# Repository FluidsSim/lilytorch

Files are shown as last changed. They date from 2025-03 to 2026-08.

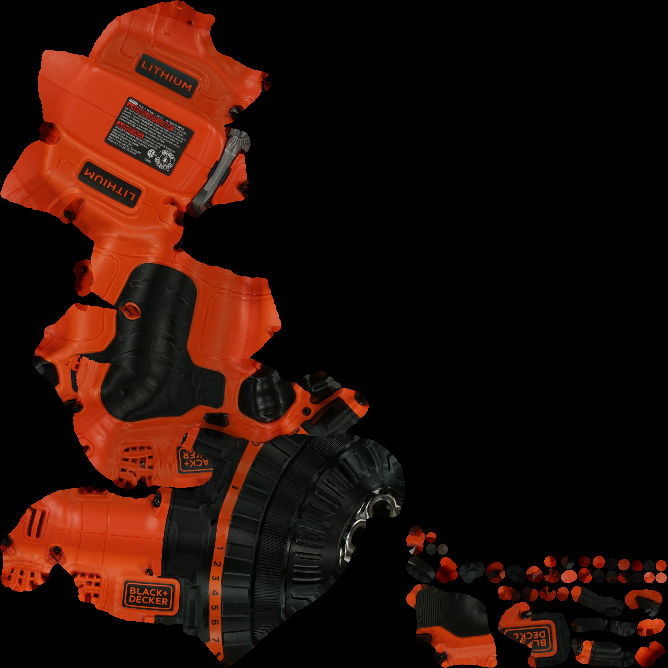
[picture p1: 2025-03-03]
lilytorch/body_solver/pytorch_volumetric_tests/tests/YcbPowerDrill/texture_map.png

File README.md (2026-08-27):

# LilyTorch

LilyTorch is a PyTorch-based 2-D/3-D incompressible-flow solver for
fluid–structure interaction. It combines a Cartesian MAC grid, BDIM2 immersed
boundaries, native C++/CUDA operators, FFT or geometric-multigrid pressure
solvers, and optional FARMS/MuJoCo coupling.

The maintained user guide, numerical documentation, API inventory, examples
index, paper links, and milestone index live in the unified
[`FluidsSim/lilytorch-docs`](https://github.com/FluidsSim/lilytorch-docs)
repository. This repository intentionally does not duplicate those pages.

## Examples

A set of examples will be made available soon. In the meantime, some simulation
examples are shown below.

<table>
<tr>
<td width="50%">

**Boat**

<video src="https://github.com/user-attachments/assets/17bb9903-24f2-4fcc-b9a0-902438b45532" width="100%" height="240" controls muted></video>

<sub>[▶ Also on YouTube](https://youtu.be/BuwlqcF3FKU)</sub>

</td>
<td width="50%">

**Submarine**

<video src="https://github.com/user-attachments/assets/08432d15-f760-4b1d-b915-560fcba9c0c9" width="100%" height="240" controls muted></video>

<sub>[▶ Also on YouTube](https://youtu.be/TZnUeeh6IvQ)</sub>

</td>
</tr>
<tr>
<td width="50%">

**Salamander — swimming 2d**

<video src="https://github.com/user-attachments/assets/084ad315-8eef-464e-81b1-3f94701fec6d" width="100%" height="240" controls muted></video>

<sub>[▶ Also on YouTube](https://youtu.be/LjBTwg80DzI)</sub>

</td>
<td width="50%">

**Zebrafish — 3-D, vorticity magnitude**

<video src="https://github.com/user-attachments/assets/42a7b2c2-9ab7-47a1-a856-ead4c0d7b4ad" width="100%" height="240" controls muted></video>

<sub>[▶ Also on YouTube](https://youtu.be/qHh5nry3F-A)</sub>

</td>
</tr>
<tr>
<td width="50%">

**Three spheres VOF**

<video src="https://github.com/user-attachments/assets/d27171a0-7b02-47c4-9880-9b576819b01f" width="100%" height="240" controls muted></video>

<sub>[▶ Also on YouTube](https://youtu.be/kHZGqutqFUI)</sub>

</td>
<td width="50%">

**1guilla robot surface swimming**

<video src="https://github.com/user-attachments/assets/07853360-651a-40a6-ac67-5831b730a184" width="100%" height="240" controls muted></video>

<sub>[▶ Also on YouTube](https://youtu.be/4YsMVhUbUNI)</sub>

</td>
</tr>
</table>

## Validation with robot experiments

### 1guilla in water - Rhodamine dye - Re~160000

<video src="https://github.com/user-attachments/assets/e63b9f63-909f-403e-aa9d-8971d2530a16" width="100%" height="600" controls muted></video>

<sub>[▶ Also on YouTube](https://youtu.be/vxCyhAP2mQc)</sub>

### 1guilla in carboxymethyl cellulose and water thick solution - Fluorescein dye - Re~100

<video src="https://github.com/user-attachments/assets/4bb6186a-d4f5-42d0-8f52-3dacf773cfbb" width="100%" height="600" controls muted></video>

<sub>[▶ Also on YouTube](https://youtu.be/748NTNWLCEs)</sub>

## Installation

Python 3.9 or newer and a C++ compiler are required. Install the appropriate
CPU or CUDA build of PyTorch first; a matching CUDA toolkit is required when
building CUDA operators.

```bash
git clone https://github.com/FluidsSim/lilytorch.git
git clone https://github.com/FluidsSim/lilytorch_examples.git

python3 -m venv .venv
source .venv/bin/activate
python -m pip install torch
python -m pip install -r lilytorch/requirements.txt
python -m pip install -e lilytorch --no-build-isolation
python -m pip install -e lilytorch_examples
```

`--no-build-isolation` is intentional: the native extension must be compiled
against the same PyTorch installation used at runtime. Set
`LILYTORCH_NO_CUDA=1` to force a CPU-only extension build.

Verify the install:

```bash
python -c "import lilytorch; from lilytorch.src import native; print(lilytorch.__version__)"
```

## FARMS/MuJoCo coupling

Initialize the pinned submodules and install the standard FARMS packages:

```bash
git -C lilytorch submodule update --init --recursive
(cd lilytorch/lilytorch/FARMS_V2 && python setup_farms.py)
```

The helper installs `farms_core`, `farms_mujoco`, and `farms_sim`. Install
`farms_amphibious` separately for cases that import it:

```bash
python -m pip install -e lilytorch/lilytorch/FARMS_V2/farms_amphibious \
  --no-build-isolation
```

## Run and test

From the directory containing both checkouts, run a maintained standalone case:

```bash
python -m lilytorch_examples.examples.standalone.runsim \
  flow_past_circle_2d.yaml
```

Run LilyTorch's companion test suite from the directory containing both
checkouts with:

```bash
python -m pytest lilytorch_examples/lilytorch_examples/tests
```

The production implementation uses native CPU/CUDA operators. There is no
separate `diffusion.py`, `kernels/` package, or selectable Python-versus-native
solver path; old `solver_method` and `use_kernels` values are compatibility
inputs only.

## License

MIT

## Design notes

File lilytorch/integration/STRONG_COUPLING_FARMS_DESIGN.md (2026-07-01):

# Strong (implicit) FSI coupling for the FARMS/MuJoCo path — design

Status: **implemented; FARMS end-to-end validation blocked by an unstable
test config** (see §16). The standalone path is implemented and validated
(`strong_coupling.py`, `fsi_rigid_body.py`, `demo_real_fsi.py`).  The
FARMS/MuJoCo implicit path is implemented in `BDIMhandler` (`_step_implicit`,
`_MujocoCheckpoint`, `_pose_source="physics"`, `_apply_forces(loads=)`); its
building blocks are individually validated, but a clean end-to-end run needs
a coupled config whose explicit baseline is stable (§16).

---

## 1. What the coupled path does today (explicit / staggered)

The dm_control runtime drives the loop. Per full step:

```
Task.before_step(action, physics):          # runs BEFORE integration
    update_sensors()
    for ext in extensions:                   # sim-extensions then animat-extensions
        ext.before_step(...)                 #   FluidExtension here -> BDIMhandler.step()
        if ext is AnimatController:           #   controller sets data.ctrl / muscle excitations
            set joint/torque/muscle ctrl
physics.step()                                # mj_step: integrate under (ctrl, xfrc_applied, contacts)
Task.after_step(physics)
```

`FluidExtension.before_step` (extensions.py) on a *full* step calls
`BDIMhandler.step(task, physics)`:

```
BDIMhandler.step:
    fs.step_(...)            # reads body poses from MuJoCo (BDIMhandler.update),
                             # advances fluid, computes loads
    self.apply_forces(...)   # assembles (F,T)+buoyancy, writes physics.data.xfrc_applied
```

Then the runtime's `physics.step()` integrates MuJoCo **once** under that
force. The fluid saw pose `pⁿ`; MuJoCo advances `pⁿ → pⁿ⁺¹` under `Fⁿ`; the
fluid never re-solves at `pⁿ⁺¹`. This is explicit Dirichlet–Neumann
staggering — unstable when added (displaced-fluid) mass ≳ body mass, which
is exactly why `force_relaxation` (a constant low-pass on `F`) exists. It
damps but does not remove the instability.

## 2. Goal

Replace the single force push with a **converged fixed-point iteration**
per step, accelerated by the existing `fsi_coupling` accelerators
(Aitken / IQN-ILS), so the coupling is stable independent of mass ratio
and `force_relaxation` is no longer needed.

## 3. The architectural constraint and the key idea

`BDIMhandler.step()` runs **inside** `before_step`, *before* the runtime's
`physics.step()`. The runtime owns the one real integration. We must not
double-integrate.

**Key idea — "leave the converged force, let FARMS integrate once"
(Option A).** Run the whole fixed-point loop *internally* inside
`BDIMhandler.step()`, using throwaway MuJoCo integrations for *prediction*
only, each undone by a checkpoint restore. When converged, restore MuJoCo
to the **start-of-step** state `sⁿ` and leave `xfrc_applied` holding the
**converged** force `F*`. Then `before_step` returns and the runtime does
its single `physics.step()`, integrating `sⁿ` under `F*` → the converged
end state. Net external effect: `xfrc_applied` carries `F*` instead of the
explicit one-shot `Fⁿ`. The FARMS control/integration pipeline is otherwise
untouched.

This is non-invasive: no changes to the runtime, the task loop, or the
controller — only `BDIMhandler.step()` gains an implicit branch.

## 4. Coupling variable

Two valid choices; **v1 recommends coupling on the force** (the Neumann
data), because it is the smallest vector and a direct upgrade of the
existing `force_relaxation`:

- **`x = applied loads`** per coupled body `[Fx,Fy,Fz,Tx,Ty,Tz] × B`
  (dim `6B`). The fixed-point map is

  ```
  H(x):  restore(mj, fluid) to start
         write x (+ buoyancy@candidate-pose) to xfrc_applied
         mj_step                      # structure: loads -> predicted pose/vel s̃
         mj_forward                   # refresh link xpos/xquat/cvel at s̃
         fluid solve at s̃ (BDIMhandler.update reads s̃ -> SDF + no-slip)
         x̃ = get_loads(+buoyancy)     # fluid -> new loads
  residual r = x̃ - x ; accelerate.
  ```

  At the fixed point the applied force equals the force the fluid produces
  for the pose that force induces — i.e. fully consistent.

- *(alternative)* **`x = generalized state (qpos, qvel)`** of the coupled
  animats. More "monolithic", but larger and needs care differencing the
  floating-base quaternion in the residual. Keep as a fallback if force
  coupling is found to converge slowly for highly articulated swimmers.

The accelerator vectors are tiny (`6B`, or tens of DOFs), so the IQN-ILS
QR solve is trivial — reuse `fsi_coupling.IQNILS` unchanged.

## 5. Checkpoint primitive (MuJoCo 3.3.7)

Use `mjSTATE_INTEGRATION` — it bundles qpos, qvel, act, time,
`qacc_warmstart`, ctrl, `qfrc_applied`, `xfrc_applied`, mocap, eq_active —
everything needed to reproduce an integration step bit-for-bit.

```python
import numpy as np, mujoco

class _MujocoCheckpoint:
    SPEC = mujoco.mjtState.mjSTATE_INTEGRATION

    def __init__(self, physics):
        self.m = physics.model.ptr
        self.d = physics.data.ptr
        self.n = mujoco.mj_stateSize(self.m, self.SPEC)
        self.buf = np.zeros(self.n, dtype=np.float64)

    def save(self):
        mujoco.mj_getState(self.m, self.d, self.buf, self.SPEC)
        return self.buf.copy()

    def restore(self, state):
        mujoco.mj_setState(self.m, self.d, state, self.SPEC)
        mujoco.mj_forward(self.m, self.d)   # refresh derived quantities
```

Fluid checkpoint reuses the existing pattern (clone `u0,v0,w0,p0`), exactly
as `FluidSolverAdapter.snapshot/restore`.

## 6. Algorithm — implicit `BDIMhandler.step()`

```python
def step_implicit(self, task, physics):
    fs   = self.fluid_solver
    it   = self.iteration
    t    = it * self.pars["solver"]["dt"]
    acc  = self.accelerator                 # fsi_coupling accelerator
    ckpt = self._mj_ckpt                     # _MujocoCheckpoint(physics)

    mj_n    = ckpt.save()                    # start-of-step MuJoCo state
    fluid_n = self._fluid_snapshot()         # clone u0,v0,w0,p0
    x = self._read_loads_vector(physics)     # initial guess: last step's loads
                                             # (0 on the first step)
    x_tilde, converged = x, False
    for k in range(1, self.max_iter + 1):
        # ---- restore both sides to start of step ----
        ckpt.restore(mj_n)
        self._fluid_restore(fluid_n)

        # ---- structure: predict pose/vel under candidate loads x ----
        self._write_loads_vector(physics, x, pose_for_buoyancy=mj_n)
        mujoco.mj_step(ckpt.m, ckpt.d)       # one full step (cb_sub_steps==1)
        mujoco.mj_forward(ckpt.m, ckpt.d)    # refresh link kinematics at s̃

        # ---- fluid: solve at predicted pose s̃ -> new loads x̃ ----
        fs.advance_and_compute_loads(fs.u0, fs.v0, fs.p0, it, t,
                                     w_vel=getattr(fs, "w0", None))
        x_tilde = self._read_loads_vector(physics, from_solver=True)

        # ---- residual + acceleration ----
        res = acc.residual_norm(x, x_tilde)
        self.last_iters, self.last_residual = k, res
        if res < self.tol * (1.0 + np.linalg.norm(x)):
            converged = True
            break
        if not np.isfinite(res):
            break
        x = acc.relax(x, x_tilde)

    acc.finalize_timestep()

    # ---- commit (Option A): leave MuJoCo at sⁿ with the converged force ----
    ckpt.restore(mj_n)
    self._write_loads_vector(physics, x_tilde, pose_for_buoyancy=mj_n)
    self._cache_forces_for_substeps(x_tilde)   # so apply_forces() re-applies F* on substeps
    fs.finalize_step(fs.u0, fs.v0, fs.p0, it,
                     w_vel=getattr(fs, "w0", None))   # plot/free-surface/release ONCE

    if not converged:
        self._handle_nonconvergence(k)             # see §9
    self.iteration += 1
```

Helpers:

- `_read_loads_vector(physics, from_solver=False)`:
  when `from_solver`, assemble from `fs.get_loads()` (the per-body
  `(F,T)`); otherwise read back what is currently in `xfrc_applied` for the
  coupled links (used for the initial guess). Flatten to `6B`.
- `_write_loads_vector(physics, x, pose_for_buoyancy)`: the body-facing
  half of the existing `_apply_forces` — scatter `x` into
  `xfrc_applied[ind, :]` for each coupled link, adding buoyancy computed at
  the **candidate** pose (reuse the existing buoyancy block). This is the
  only place that touches `xfrc`.
- `_cache_forces_for_substeps`: store `F*` in the same buffers
  `apply_forces()` reads, so intermediate MuJoCo substeps re-apply `F*`.

Note the fluid solve uses `advance_and_compute_loads` / `get_loads` /
`finalize_step` — the **same** drift-free methods the standalone
`FluidSolverAdapter` calls. `BDIMhandler.update` (which reads poses from
`physics`) runs inside `advance_and_compute_loads` via
`composite_body.update`, so it automatically sees the predicted pose `s̃`.

## 7. Requirements / constraints

1. **`cb_sub_steps == 1` for implicit mode.** The fluid advances once per
   full step; the prediction does one `mj_step`. With `cb_sub_steps > 1`
   the real integration is several substeps under the held force, so the
   prediction must loop `cb_sub_steps` `mj_step`s (re-applying the held
   force each) to match. v1 asserts `cb_sub_steps == 1`; the generalization
   is a `for _ in range(cb_sub_steps): mj_step` in the predict block.

2. **Order `FluidExtension` *after* the `AnimatController`.** The controller
   sets `data.ctrl` inside the same `before_step` pass; if Fluid runs first,
   the prediction `mj_step` uses *stale* ctrl. Putting Fluid last (or
   pre-computing the excitations, which are open-loop functions of
   `(iteration, time)`) makes the prediction use the same actuation the
   real step will use. Document/auto-check in `FluidExtension.from_options`.

3. **Buoyancy is pose-dependent** → recompute it inside
   `_write_loads_vector` at the candidate pose each sweep (the existing
   buoyancy block already reads `comp.com_pos`, which reflects the pose
   after `BDIMhandler.update`).

4. **Determinism.** `mjSTATE_INTEGRATION` includes `qacc_warmstart`, so the
   constraint solver warm-starts identically each restore → the prediction
   `mj_step` and the runtime's real `mj_step` produce identical `s̃` for
   identical `(sⁿ, ctrl, xfrc)`. Verify this equality once in validation
   (it is the correctness anchor for Option A).

## 8. Config surface

```yaml
body:
  coupling:
    scheme: implicit          # "explicit" (default, today) | "implicit"
    accelerator: iqn-ils      # iqn-ils | aitken | constant
    reuse: 2                  # IQN-ILS time-window reuse
    tol: 1.0e-4               # relative interface-residual tolerance
    max_iter: 30
    # force_relaxation is ignored when scheme == implicit
```

`BDIMhandler.__init__` builds `self.accelerator =
fsi_coupling.make_accelerator(...)`, `self._mj_ckpt`, and binds
`self.step = self.step_implicit if scheme == "implicit" else self.step_explicit`
(the current `step` becomes `step_explicit`, unchanged).

## 9. Edge cases & robustness

- **Non-convergence**: if `max_iter` is hit, fall back to the
  last-accepted `x_tilde` (best effort) and log a warning with the residual.
  Optionally trigger a one-step `force_relaxation`-style damped apply as a
  safety net. Never propagate NaNs — `check_explosion` still runs in
  `finalize_step`.
- **Contacts** (sphere near a wall, paddling on ground): handled naturally
  by `mj_step` in the prediction; no special treatment. The added
  stiffness can slow convergence — IQN-ILS reuse helps.
- **Multiple animats / partial coupling**: `_read/_write_loads_vector`
  iterate the same `comp.bodies / body_ids` the explicit path already uses;
  the coupling vector is the concatenation over coupled links only.
- **Cost**: `N` fluid solves per step (N = sweeps). Expect `N≈2–4` after
  the first step thanks to IQN-ILS reuse; the first step of a sim costs
  more. This is the price of stability; it replaces sims that diverge or
  need tiny `dt` + `force_relaxation`.

## 10. Reuse of existing code

- Accelerators: `fsi_coupling.{IQNILS,AitkenRelaxation,ConstantUnderRelaxation}`
  — unchanged.
- Fluid stepping: `FluidSolver.advance_and_compute_loads / get_loads /
  finalize_step` — unchanged (already used by `FluidSolverAdapter`).
- Force assembly/scatter + buoyancy: factor the body-facing half of the
  current `_apply_forces` into `_write_loads_vector` so explicit and
  implicit share it.

## 11. Validation plan

1. **Determinism check** (§7.4): one internal predict `mj_step` vs the
   runtime's real `mj_step` from the same checkpoint must give identical
   `qpos/qvel`. Anchors Option A.
2. **Single sphere drop** (`single_sphere_drop_coquerelle` /
   `_gazzola`): run explicit (current) vs implicit. Expect implicit to (a)
   run stably with the true `rho_body` (no `bdim_mu0_projection` / equal-
   density workaround), (b) remove the iteration-~12,500 blow-up, (c) match
   the published terminal velocity / `Cd(Re)`. Report sweeps/step.
3. **1guilla full tank**: confirm implicit removes the need for
   `force_relaxation` even with `convexify=True` overlap (see
   `project_convexify_overlap_instability`), or quantify the remaining gap.

## 12. Open questions

- Force-coupling vs state-coupling convergence for highly articulated
  swimmers (many controlled joints): start with force; switch the coupling
  vector if needed (the accelerator is agnostic).
- Whether to sub-iterate the *whole* animat state or only the floating
  base + wetted-link velocities (reduce vector size / ignore stiff
  controlled joints in the interface residual).
- Interaction with the interactive viewer (which can clear `xfrc`): the
  per-substep `apply_forces` re-application already handles this; confirm it
  still holds with Option A.
```

---

## 13. Design review — findings & required revisions

Reviewed against the actual code paths. Two **blocking** issues invalidate
the §6 algorithm as written; several minor corrections follow.

### BLOCKER 1 — the fluid reads FARMS *sensor buffers*, not `physics.data`

`BDIMhandler.update → gather_data(iteration)` (BDIMhandler.py:343) reads
poses/velocities from `exp_data.sensors.links.com_positions()[iteration]`
(and `urdf_*`, `*_velocities`), **not** from `physics.data.xpos/xquat/cvel`.
Those sensor arrays are written by `Task.update_sensors(physics)`
(task.py:249, `index = iteration % buffer_size`), called once at the top of
`Task.before_step`.

Consequence: an internal `mj_step` + `mj_forward` updates `physics.data`
but **not** what the fluid reads — the fluid would keep solving at the
start-of-step pose every sweep, and the coupling could never converge to a
moved pose.

**Revision:** after each prediction `mj_step`, call
`task.update_sensors(physics, links_only=True)` to push the predicted pose
`s̃` into the sensor buffer that `gather_data` reads. The corrected sweep:

```
restore(mj→sⁿ, fluid→fluidⁿ)
write candidate force x → xfrc
mj_step ; mj_forward                          # physics.data := s̃
task.update_sensors(physics, links_only=True) # sensor buffer[it] := s̃   ← ADDED
fs.advance_and_compute_loads(...)             # gather_data now reads s̃
x̃ = get_loads(+buoyancy)
```

Also note: the MuJoCo checkpoint (`mjSTATE_INTEGRATION`) does **not** cover
the FARMS `AnimatData` sensor buffers. We don't need to restore them
(each sweep overwrites buffer[it] via `update_sensors`), but be aware
buffer[it] is left holding the last `s̃` after the step (see Minor 3).

### BLOCKER 2 — the "single `mj_step`" prediction is unverified

The real integration is `self._env.step()` → dm_control
`physics.step(n_sub_steps)` (simulation.py:270/311/333), where
`n_sub_steps = physics.num_sub_steps` and there is also a `legacy_step`
toggle (simulation.py:58) — *separate from* FARMS `cb_sub_steps`. So the
real step may be **multiple** `mj_step`s, and possibly a custom stepping
path.

**Revision:** the prediction must replicate the real integration exactly,
i.e. `n_sub_steps × (cb_sub_steps==1)` `mj_step`s through the same path the
runtime uses (prefer calling `physics.step(n_sub_steps)` on the checkpointed
data, not a bare `mj_step`, unless `legacy_step` changes that). The §11.1
**determinism check is therefore a blocking prerequisite, not a nicety**:
confirm `predict-integration(sⁿ, ctrl, xfrc) == runtime-integration` to
machine precision before trusting Option A. Resolve `num_sub_steps`,
`cb_sub_steps`, and `legacy_step` for the target sphere-drop config first.

### Minor 1 — commit `x`, not `x_tilde`

At convergence the fluid's committed solve was performed at pose
`s̃ = integrate(sⁿ, x)` where `x` is the **last candidate** force (the
prediction used `x`, not `x̃`). To keep {committed force, fluid pose,
FARMS integration} mutually consistent, commit **`x`** to `xfrc` (FARMS then
reproduces exactly the `s̃` the fluid solved at). `x ≈ x̃` within `tol`, so
the difference is small, but `x` is the correct choice. (Fix the §6
pseudocode: `_write_loads_vector(physics, x, ...)`.)

### Minor 2 — buoyancy is outside the coupling vector

Buoyancy is pose-dependent and recomputed each sweep at write time, so the
interface residual is on the **hydrodynamic** load only. This is fine
(buoyancy is a deterministic function of the converging pose), but state it
explicitly and make sure `get_loads` (hydro) and the buoyancy add are not
double-counted.

### Minor 3 — sensor buffer left at `s̃` after commit (logging)

Because Option A restores MuJoCo to `sⁿ` but the sensor buffer at `it` holds
the last prediction `s̃`, the *logged* link pose at iteration `it` is the
end-of-step prediction rather than the start pose. Decide intended
semantics; if start-of-step logging is desired, re-run
`update_sensors(physics)` after the final `ckpt.restore(mj→sⁿ)`.

### Minor 4 — iteration-index alignment

`gather_data` indexes with `BDIMhandler.iteration`; `update_sensors`/buffers
index with `Task.iteration`. They both start at 0 and advance once per full
step, but the implicit path must keep them aligned (and respect
`buffer_size`, given `gather_data` uses a raw `[iteration]` index while
writes use `iteration % buffer_size`).

### Minor 5 — cost

Each sweep now also runs `update_sensors` (links) in addition to a full
fluid solve and `n_sub_steps` `mj_step`s. Still `O(sweeps)`; acceptable, but
the per-sweep constant is higher than the §9 estimate implied.

### What still holds

- Option A (run the loop inside `before_step`; leave `sⁿ` + converged force;
  FARMS integrates once) remains valid **with** the `update_sensors`
  propagation and the exact-integration replication added.
- Checkpoint primitive (`mjSTATE_INTEGRATION`) — correct/sufficient for the
  MuJoCo side (covers qpos/qvel/act/time/warmstart/ctrl/qfrc/xfrc); just
  remember it excludes the FARMS sensor buffers.
- Force coupling vector, `fsi_coupling` accelerator reuse, and the
  `advance_and_compute_loads / get_loads / finalize_step` fluid path —
  unchanged and valid.
- Requirements §7 (cb_sub_steps==1, Fluid ordered after the controller,
  pose-dependent buoyancy) — still required; add "resolve num_sub_steps /
  legacy_step" to the list.

### Recommended first implementation step (unchanged, now justified)

Implement `_MujocoCheckpoint` + the **determinism check** against a real
sphere-drop config, explicitly resolving `num_sub_steps`, `cb_sub_steps`,
`legacy_step`, and confirming `update_sensors`→`gather_data` round-trips the
predicted pose. Only once that anchor passes is the rest safe to wire.

---

## 14. Revised data path — read `physics.data` directly (supersedes Blocker 1)

The cleaner fix for Blocker 1 is to **read link kinematics straight from
`physics.data`** in the implicit path, instead of the FARMS sensor buffers.
This is exactly what FARMS' own `SwimmingExtension` does
(`swimming/extension.py:205`: `physics.data.xmat[indices]`), and the
per-link MuJoCo body-id map is the one BDIMhandler already uses for forces:
`indices = task.maps[animat_i]['sensors']['data2xfrc']`.

Field mapping (MuJoCo → what `gather_data` returns), with FARMS unit
scaling so values match the SI sensor path:

| gather_data output | physics.data source | units |
|---|---|---|
| `urdf_pos` (link frame origin) | `data.xpos[ind]` | `÷ units.meters` |
| `R` (link orientation) | `data.xmat[ind].reshape(3,3)` | — |
| `com_pos` (link COM) | `data.xipos[ind]` | `÷ units.meters` |
| `lin_vel` (COM linear vel) | `mj_objectVelocity(... mjOBJ_XBODY, ind, flg_local=0)` linear part | `÷ units.velocity` |
| `ang_vel` (COM angular vel) | same call, angular part | `÷ (units.velocity/units.meters)` |

Because the internal prediction (`physics.step` / `mj_step` + `mj_forward`)
updates `physics.data`, the fluid now sees the predicted pose **with no
`update_sensors` round-trip**. This removes the §13 Blocker-1 workaround and
Minor 3/4 (no sensor-buffer mutation, no buffer/iteration-index coupling).
Revised sweep:

```
restore(mj→sⁿ, fluid→fluidⁿ)
write candidate force x → xfrc
physics.step(n_sub_steps)            # SAME call the runtime uses (see §15)
fs.advance_and_compute_loads(...)    # gather_data(source="physics") reads physics.data = s̃
x̃ = get_loads
```

**Risk to control:** `gather_data` is shared with the *explicit* (validated)
path. To avoid silently changing existing coupled sims, **do not replace**
the sensor path — *parametrize* it: `gather_data(iteration, source="sensors"
| "physics")`, explicit keeps `"sensors"`, implicit uses `"physics"`. Then
add an **equivalence test**: at the start-of-step pose `sⁿ`, the two sources
must return matching `(urdf_pos, R, com_pos, lin_vel, ang_vel)` to tight
tolerance. Positions/orientation are trivial (`xpos/xipos/xmat`); the
**velocities are the subtle part** — match the exact `mj_objectVelocity`
convention (com-based, global frame) and unit scaling FARMS uses to fill the
sensors. The equivalence test is the gate for the data path; the §11.1
determinism test is the gate for the integration.

## 15. Blocker 2, downgraded — use the runtime's own integration call

Rather than reimplement the integration with a bare `mj_step` (and guess at
`num_sub_steps` / `legacy_step`), the prediction should invoke the **same**
call the dm_control runtime uses after `before_step`:
`physics.step(self._env._n_sub_steps)` (simulation.py:270 → dm_control
`Environment.step` → `physics.step(n_sub_steps)`). On the checkpointed data
this reproduces the real integration by construction — there is nothing to
re-derive. Blocker 2 then reduces to a single assertion (§11.1): predict via
`physics.step(n)`, read `s̃`; restore; let the runtime step; assert the
runtime's `s̃` equals the predicted one. The only residual is whether
`legacy_step=True` routes through a non-`physics.step` path — which the
assertion catches immediately. So: **Blocker 2 is "use the same call + one
test", not a redesign.**

---

## 16. Implementation status (steps 1–3 done; FARMS validation blocked)

**Implemented & validated (building blocks):**
- §1 pose-source data path: `gather_data(_pose_source="physics")` + `_gather_data_physics`. Equivalence to the sensor path **verified on a real farmsim sphere-drop run** (iters 0,1 PASS). `test_pose_source.py` (3 convention tests pass).
- §5 checkpoint: `_MujocoCheckpoint` (mjSTATE_INTEGRATION). Determinism/reproducibility verified — `test_mujoco_checkpoint.py` (3 pass).
- `_apply_forces` refactored to accept a `loads=` override (shared buoyancy/scaling/write); explicit `loads=None` path is byte-identical (confirmed: original and refactored both explode coquerelle at iter ~5, i.e. no regression).
- §6 implicit step: `_step_implicit` (force coupling, Option A, checkpoint/restore loop, IQN-ILS via `fsi_coupling`), config surface `body.coupling.{scheme,accelerator,reuse,tol,max_iter,predict_substeps}`. Dispatched from `step()`; explicit path renamed `_step_explicit` (unchanged).

**FARMS end-to-end validation: BLOCKED by config, not implemented bug.**
- The only coupled config exercised (`single_sphere_drop_coquerelle`) has an **unstable explicit baseline**: the *original* (pre-work) code explodes at iteration 5 (`|u|_max=2.4e6 > 100`). It is one of the known instability cases (see `INSTABILITY_ANALYSIS`, `project_bdim_pressure_band`), so it cannot validate the implicit scheme.
- Under implicit coupling the same config diverges at step 0 (force → ~1e6): a single in-loop fluid solve at the *predicted moving-body* pose drives `|u|` to ~1e5 in one solve (gathered velocity `[0,-0.098]` is correct; gravity_z=-980 ⇒ cm units; pose correct). `bdim_mu0_projection: True` did **not** change this. Because the explicit baseline is itself unstable, the step-0 divergence cannot be cleanly attributed to an implicit bug vs the config's inherent fragility (the implicit scheme imposes the moving body immediately, hitting the instability sooner than explicit's lagged ramp-up).

**Next steps to actually validate:**
1. Find/produce a **stable coupled config** (explicit baseline runs without `check_explosion`): e.g. a swimmer at moderate Re, or a sphere-drop with grid/dt/eps tuned so the explicit baseline is at least marginally stable. Run explicit vs implicit and compare.
2. If a target is meant to be the *unstable* sphere-drop (the case the project wants implicit to cure), first establish that implicit *converges* per step on a stable case, then test whether it tames the unstable one — instrument the per-sweep residual to confirm the fixed-point map is contractive (it should be for `rho_body/rho>1`).
3. Resolve the impulsive-startup question: whether a single solve at the predicted moving-body pose on the start-of-step fluid field is well-posed, or whether the first sweep should solve at the start pose (explicit predictor) before predicting.

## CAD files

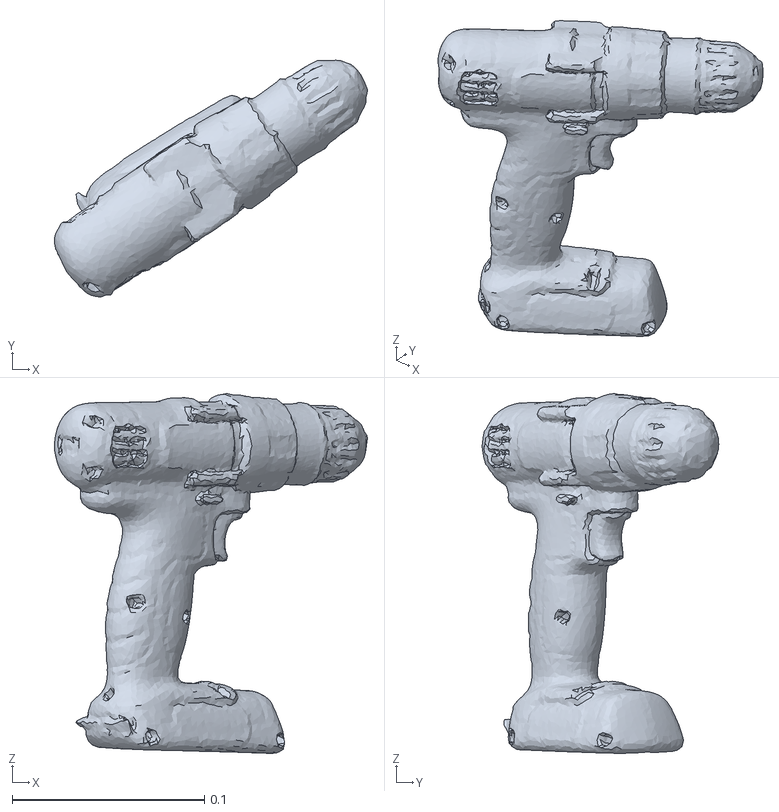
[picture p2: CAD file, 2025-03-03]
lilytorch/body_solver/mesh_examples/textured_simple_reoriented.obj
0.163 x 0.123 x 0.187

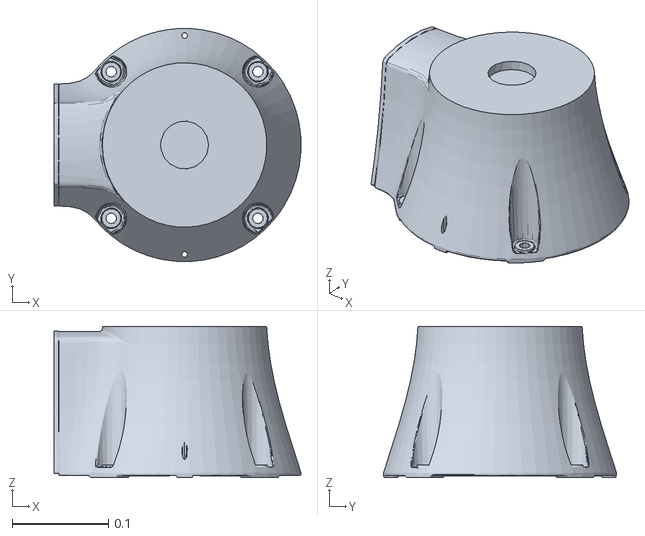
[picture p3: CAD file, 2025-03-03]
lilytorch/body_solver/mesh_examples/URDF_models/meshes_iiwa/link_0.stl
0.257 x 0.243 x 0.158

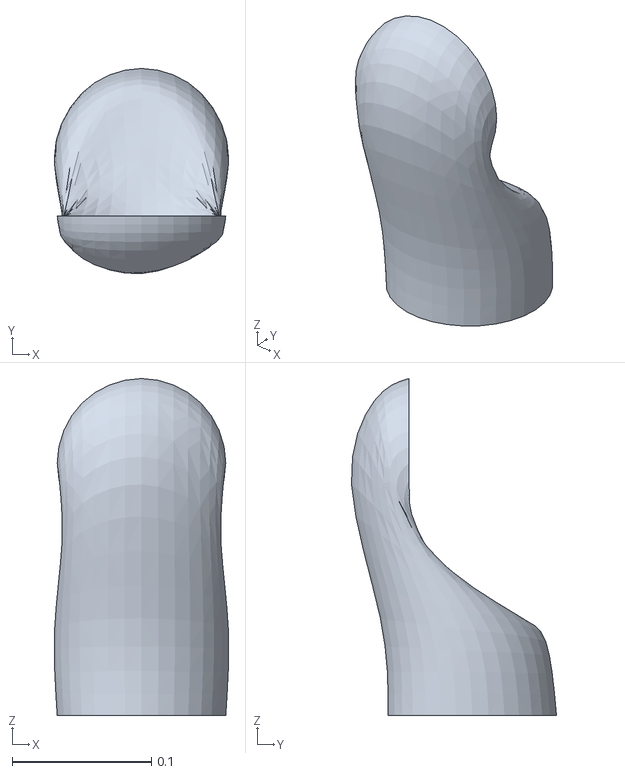
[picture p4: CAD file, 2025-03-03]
lilytorch/body_solver/mesh_examples/URDF_models/meshes_kuka_lwr/arm_segment_last.stl
0.125 x 0.147 x 0.242

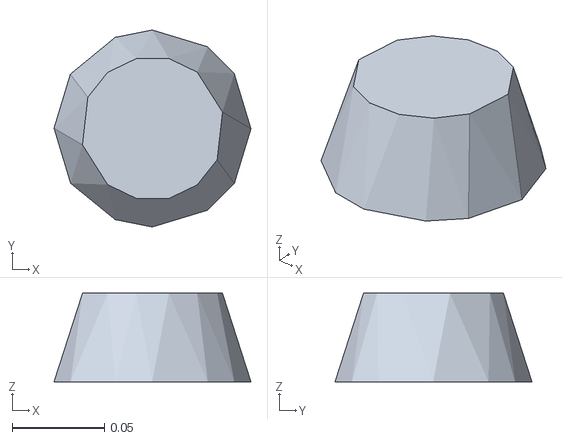
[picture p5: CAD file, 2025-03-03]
lilytorch/body_solver/mesh_examples/URDF_models/meshes_kuka_lwr/convex/arm_flanche_convex.stl
0.107 x 0.107 x 0.048

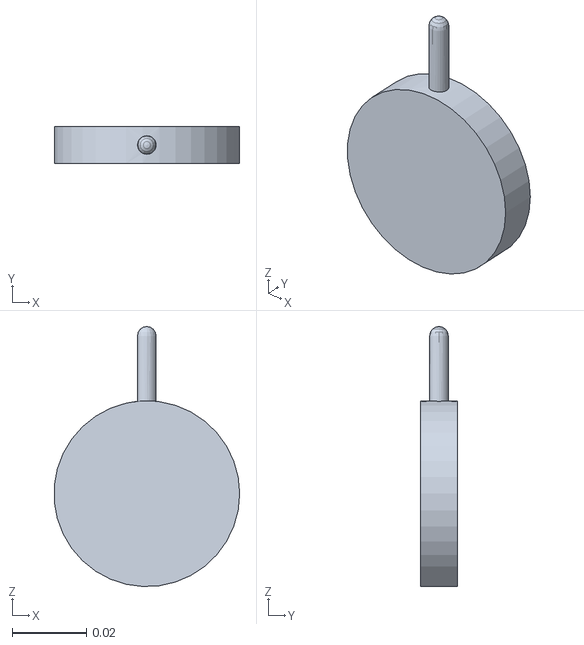
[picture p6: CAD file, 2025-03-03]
lilytorch/body_solver/pytorch_volumetric_tests/tests/probe.obj
0.0499 x 0.01 x 0.07

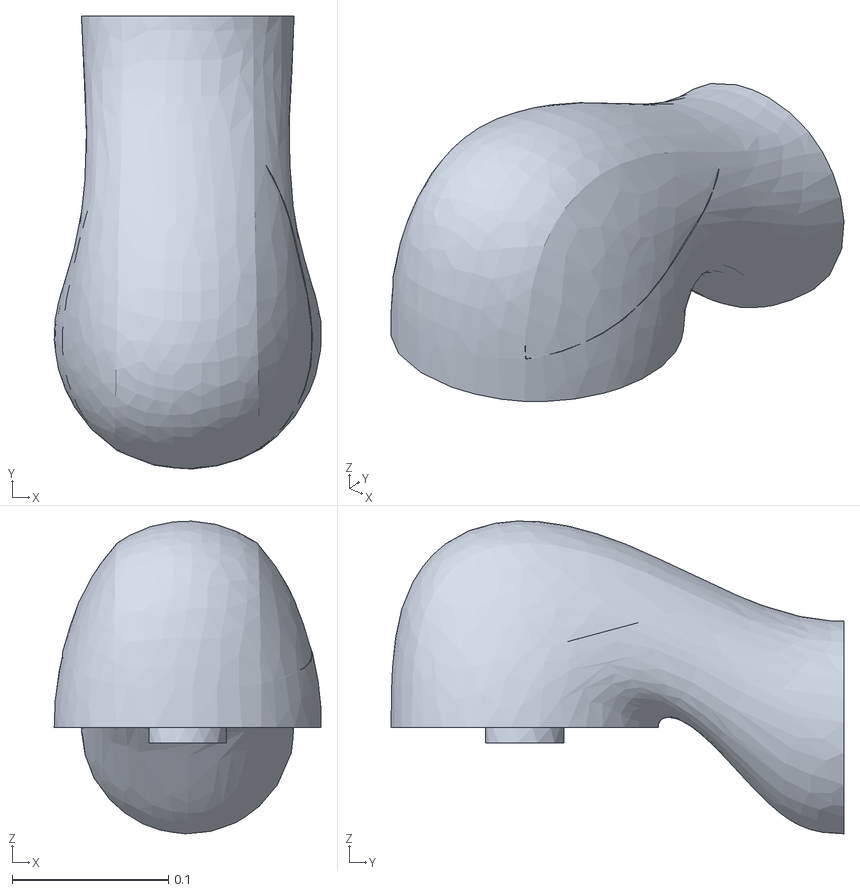
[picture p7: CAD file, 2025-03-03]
lilytorch/body_solver/mesh_examples/URDF_models/meshes_iiwa/link_2.stl
0.171 x 0.29 x 0.2

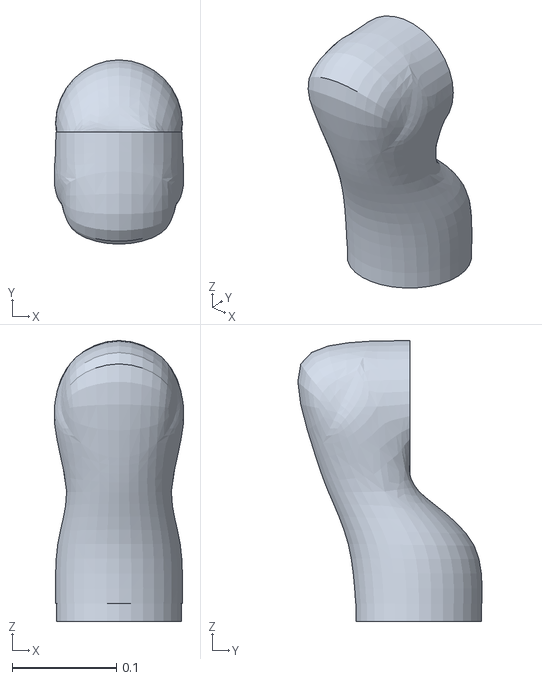
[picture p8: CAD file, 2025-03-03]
lilytorch/body_solver/mesh_examples/URDF_models/meshes_kuka_lwr/arm_segment_b.stl
0.124 x 0.177 x 0.269

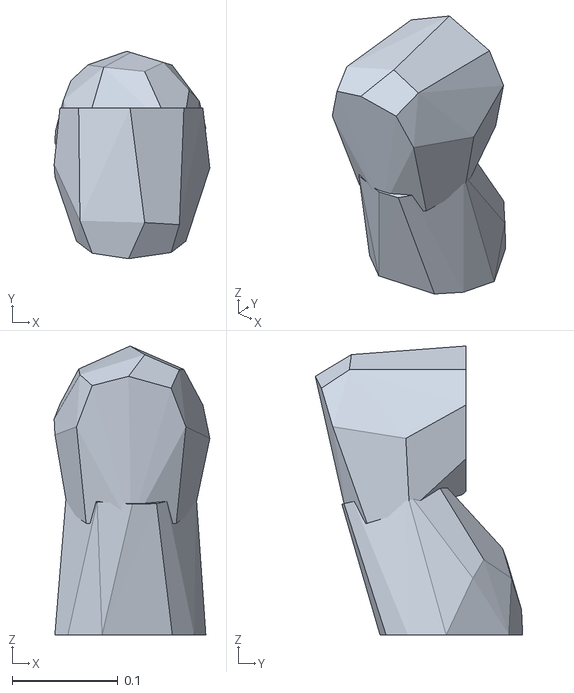
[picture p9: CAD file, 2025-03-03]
lilytorch/body_solver/mesh_examples/URDF_models/meshes_kuka_lwr/convex/arm_segment_a_convex.stl
0.148 x 0.197 x 0.274

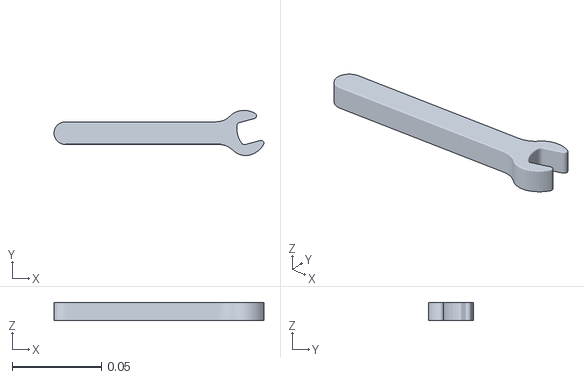
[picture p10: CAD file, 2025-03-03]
lilytorch/body_solver/pytorch_volumetric_tests/tests/offset_wrench_nogrip.obj
0.117 x 0.0253 x 0.0101

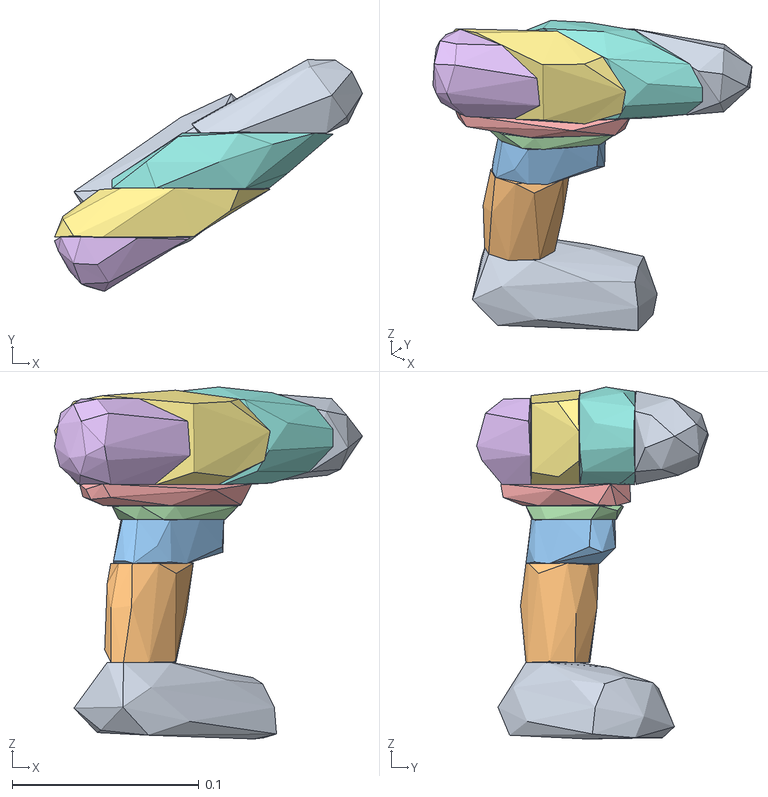
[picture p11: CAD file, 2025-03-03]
lilytorch/body_solver/pytorch_volumetric_tests/tests/YcbPowerDrill/collision_vhacd.obj
0.165 x 0.124 x 0.188
textured_simple_reoriented.004_hull_1_textured_simple_reoriente
textured_simple_reoriented.004_hull_2_textured_simple_reoriente
textured_simple_reoriented.004_hull_3_textured_simple_reoriente
textured_simple_reoriented.004_hull_4_textured_simple_reoriente
textured_simple_reoriented.004_hull_5_textured_simple_reoriente
textured_simple_reoriented.004_hull_6_textured_simple_reoriente
textured_simple_reoriented.004_hull_7_textured_simple_reoriente
textured_simple_reoriented.004_hull_8_textured_simple_reoriente
textured_simple_reoriented.004_hull_9_textured_simple_reoriente

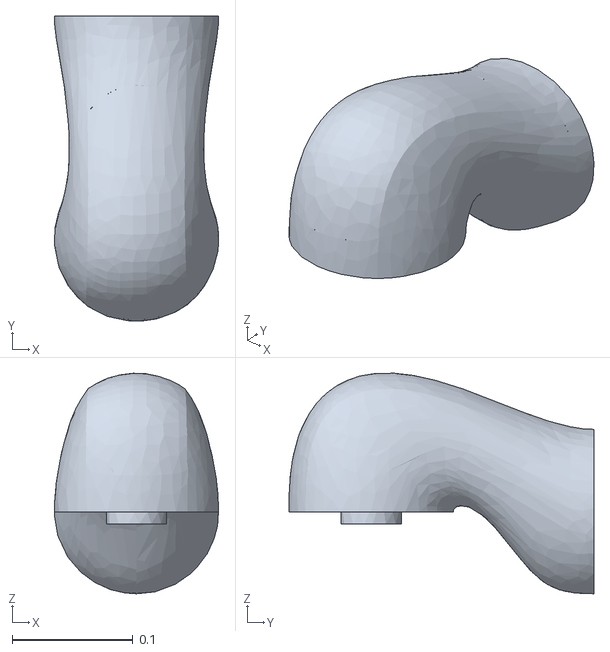
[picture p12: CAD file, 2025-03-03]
lilytorch/body_solver/mesh_examples/URDF_models/meshes_iiwa/link_4.stl
0.136 x 0.252 x 0.183

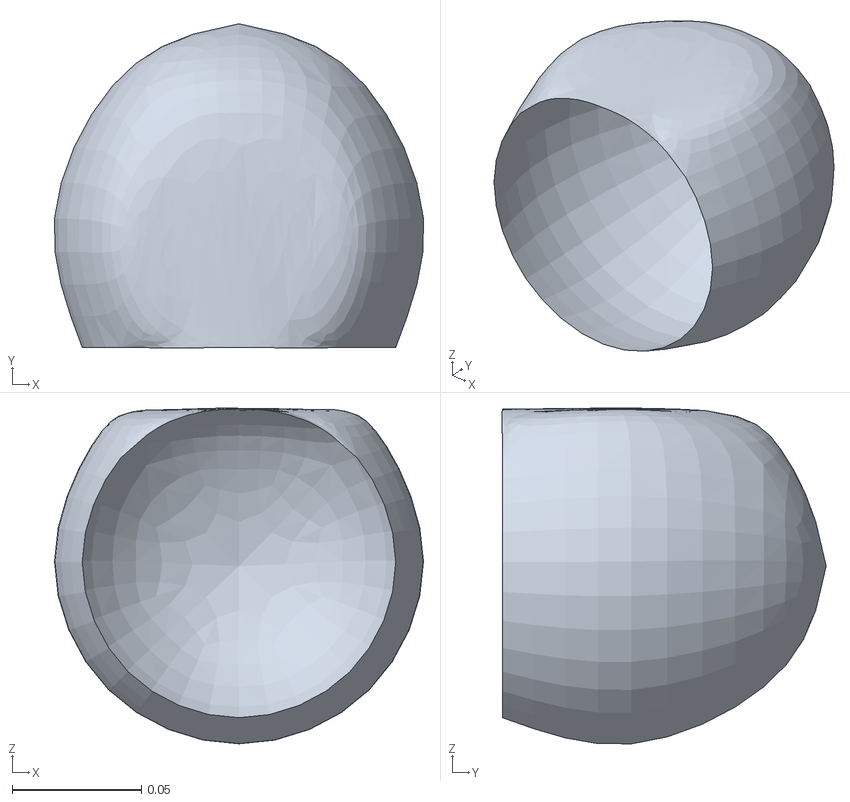
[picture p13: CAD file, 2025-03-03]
lilytorch/body_solver/mesh_examples/URDF_models/meshes_kuka_lwr/arm_wrist.stl
0.143 x 0.125 x 0.13

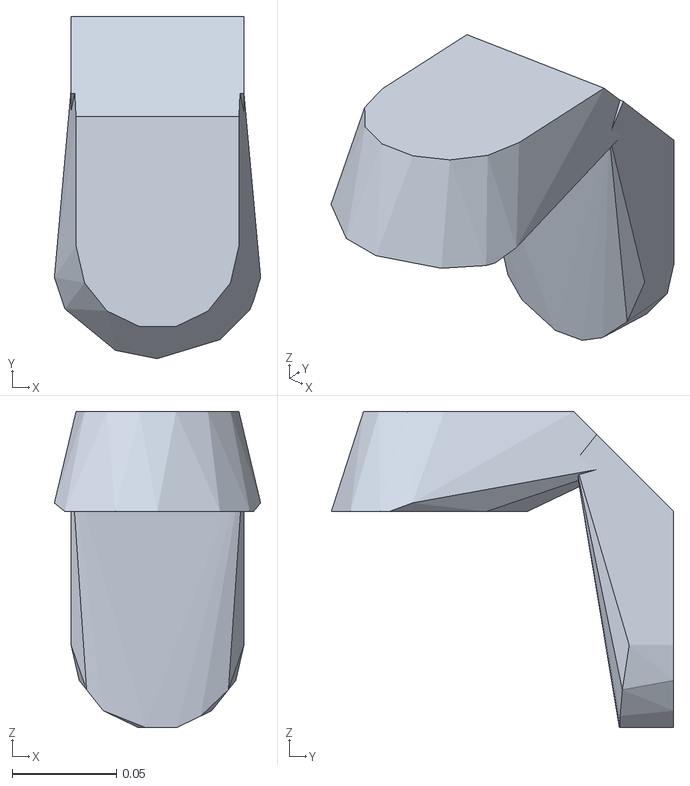
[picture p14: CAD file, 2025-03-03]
lilytorch/body_solver/mesh_examples/URDF_models/meshes_kuka_lwr/convex/arm_flanche_angle_convex.stl
0.099 x 0.164 x 0.152

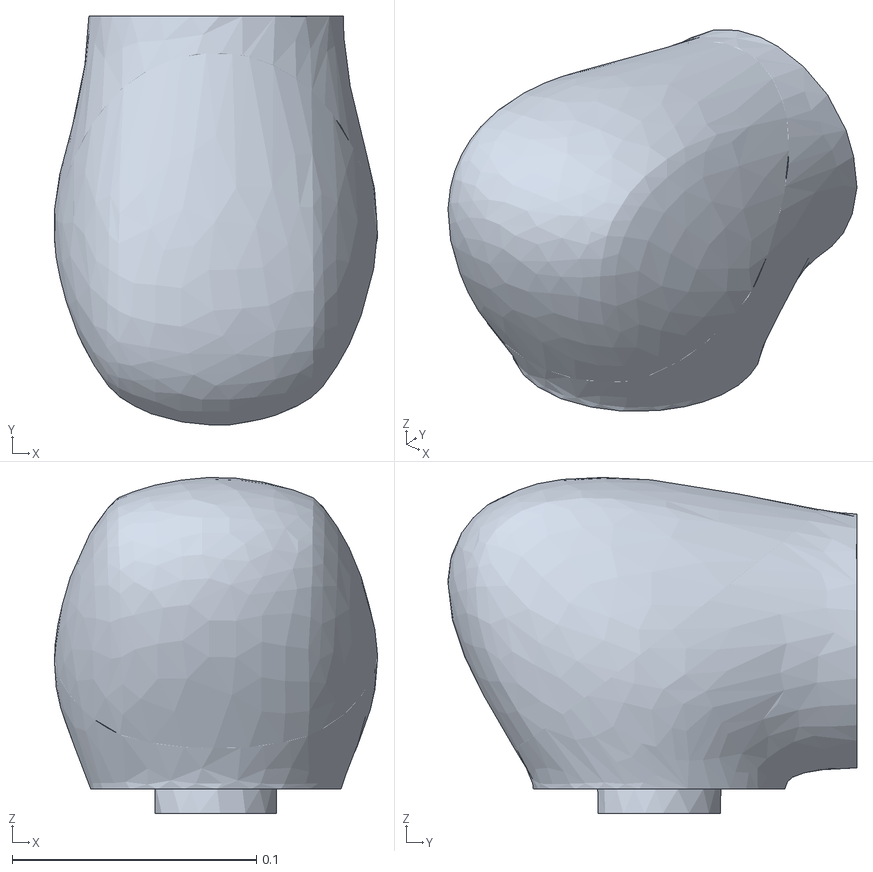
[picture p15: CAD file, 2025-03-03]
lilytorch/body_solver/mesh_examples/URDF_models/meshes_iiwa/link_6.stl
0.132 x 0.167 x 0.138

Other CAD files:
lilytorch/body_solver/mesh_examples/URDF_models/meshes_kuka_lwr/arm_flanche_angle.stl
lilytorch/body_solver/mesh_examples/URDF_models/meshes_kuka_lwr/convex/arm_segment_b_convex.stl
lilytorch/body_solver/mesh_examples/URDF_models/meshes_iiwa/link_3.stl
lilytorch/body_solver/mesh_examples/URDF_models/meshes_iiwa/link_1.stl
lilytorch/body_solver/mesh_examples/URDF_models/meshes_iiwa/link_5.stl
lilytorch/body_solver/mesh_examples/URDF_models/meshes_iiwa/link_7.stl
lilytorch/body_solver/mesh_examples/URDF_models/meshes_kuka_lwr/arm_base.stl
lilytorch/body_solver/mesh_examples/URDF_models/meshes_kuka_lwr/arm_flanche.stl
lilytorch/body_solver/mesh_examples/URDF_models/meshes_kuka_lwr/arm_segment_a.stl
lilytorch/body_solver/mesh_examples/URDF_models/meshes_kuka_lwr/convex/arm_base_convex.stl
lilytorch/body_solver/mesh_examples/URDF_models/meshes_kuka_lwr/convex/arm_segment_last_convex.stl
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

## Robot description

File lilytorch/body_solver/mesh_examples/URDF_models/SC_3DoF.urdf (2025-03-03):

<?xml version="1.0" ?>

<robot name="Chaser">

  <!-- Colors -->
  <material name="Grey">
    <color rgba="0.2 0.2 0.2 1.0"/>
  </material>
  <material name="Orange">
    <color rgba="1.0 0.423529411765 0.0392156862745 1.0"/>
  </material>
  <material name="Blue">
  <color rgba="0.5 0.7 1.0 1.0"/>      
  </material>
  <material name="Red">
    <color rgba="1 0 0 1.0"/>      
  </material>



  <!--Spacecraft-->
  <link name="Spacecraft">
    <inertial>
      <origin rpy="0 0 0" xyz="0 0 0"/>
      <mass value="100"/>
      <inertia ixx="9.3" ixy="0" ixz="0" iyy="9.3" iyz="0" izz="9.3"/>
    </inertial>
    <visual>
      <origin rpy="0 0 0" xyz="0 0 0"/>
      <geometry>
        <box size="0.75 0.75 0.75" />
      </geometry>
      <material name="Grey"/>
    </visual>
  </link>
  <!-- Joint to Manipulator -->
  <joint name="Spacecraft_Manipulator_Joint" type="fixed">
    <parent link="Spacecraft"/>
    <child link="Link_0"/>
    <origin rpy="0 0 0" xyz="0 0 0.375"/>
    <axis xyz="0 0 1"/>
  </joint>



  
  <!--Manipulator-->
  <!-- Link 0 -->
  <link name="Link_0">
    <inertial>
      <origin rpy="0 0 0" xyz="0 0 0.125"/>
      <mass value="5"/>
      <inertia ixx="0.05" ixy="0" ixz="0" iyy="0.05" iyz="0" izz="0.05"/>
    </inertial>
    <visual>
      <origin rpy="0 0 0" xyz="0 0 0.125"/>
      <geometry>
        <cylinder radius="0.05" length="0.25"/>
      </geometry>
      <material name="Grey"/>
    </visual>
  </link>
  <!-- Joint 1 -->
  <joint name="Joint_1" type="revolute">
    <parent link="Link_0"/>
    <child link="Link_1"/>
    <origin rpy="0 0 0" xyz="0 0 0.25"/>
    <axis xyz="0 0 1"/>
  </joint>
    <!-- Link 1 -->
  <link name="Link_1">
    <inertial>
      <origin rpy="0 0 0" xyz="0 0 0.1"/>
      <mass value="5"/>
      <inertia ixx="0.05" ixy="0" ixz="0" iyy="0.05" iyz="0" izz="0.05"/>
    </inertial>
    <visual>
      <origin rpy="0 0 0" xyz="0 0 0.1"/>
      <geometry>
        <cylinder radius="0.05" length="0.2"/>
      </geometry>
      <material name="Blue"/>
    </visual>
    <visual>
      <origin rpy="0 0 0" xyz="0 0 0"/>
      <geometry>
        <cylinder radius="0.1" length="0.1"/>
      </geometry>
      <material name="Orange"/>
    </visual>
  </link>
  <!-- Joint 2 -->
  <joint name="Joint_2" type="revolute">
    <parent link="Link_1"/>
    <child link="Link_2"/>
    <origin rpy="0 0 0" xyz="0 0 0.2"/>
    <axis xyz="1 0 0"/>
  </joint>
    <!-- Link 2 -->
  <link name="Link_2">
    <inertial>
      <origin rpy="0 0 0" xyz="0 0 0.375"/>
      <mass value="10"/>
      <inertia ixx="0.1" ixy="0" ixz="0" iyy="0.1" iyz="0" izz="0.1"/>
    </inertial>
    <visual>
      <origin rpy="0 0 0" xyz="0 0 0.375"/>
      <geometry>
        <cylinder radius="0.05" length="0.75"/>
      </geometry>
      <material name="Blue"/>
    </visual>
    <visual>
      <origin rpy="0 1.5708 0" xyz="0 0 0"/>
      <geometry>
        <cylinder radius="0.075" length="0.15"/>
      </geometry>
      <material name="Orange"/>
    </visual>
  </link>
  <!-- Joint 3 -->
  <joint name="Joint_3" type="revolute">
    <parent link="Link_2"/>
    <child link="Link_3"/>
    <origin rpy="0 0 0" xyz="0 0 0.75"/>
    <axis xyz="1 0 0"/>
  </joint>
    <!-- Link 3 -->
  <link name="Link_3">
    <inertial>
      <origin rpy="0 0 0" xyz="0 0 0.375"/>
      <mass value="10"/>
      <inertia ixx="0.1" ixy="0" ixz="0" iyy="0.1" iyz="0" izz="0.1"/>
    </inertial>
    <visual>
      <origin rpy="0 0 0" xyz="0 0 0.375"/>
      <geometry>
        <cylinder radius="0.05" length="0.75"/>
      </geometry>
      <material name="Blue"/>
    </visual>
    <visual>
      <origin rpy="0 1.5708 0" xyz="0 0 0"/>
      <geometry>
        <cylinder radius="0.075" length="0.15"/>
      </geometry>
      <material name="Orange"/>
    </visual>
  </link>
  <!-- Joint End-Effector -->
  <joint name="Joint_EE" type="fixed">
    <parent link="Link_3"/>
    <child link="Link_EE"/>
    <origin rpy="0 0 0" xyz="0 0 0.75"/>
    <axis xyz="1 0 0"/>
  </joint>
    <!-- End-Effector -->
  <link name="Link_EE">
    <inertial>
      <origin rpy="0 0 0" xyz="0 0 0"/>
      <mass value="0"/>
      <inertia ixx="0" ixy="0" ixz="0" iyy="0" iyz="0" izz="0"/>
    </inertial>
    <visual>
      <origin rpy="0 0 0" xyz="0 0 0"/>
      <geometry>
        <sphere radius="0.1"/>
      </geometry>
      <material name="Red"/>
    </visual>
  </link>
  
</robot>

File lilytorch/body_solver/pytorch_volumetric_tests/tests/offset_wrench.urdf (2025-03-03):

<robot name="wrench">
  <material name="trans_grey">
    <color rgba="0.2 0.2 0.2 0.5"/>
  </material>
  <link name="link_x_trans"/>
  <link name="link_y_trans"/>
  <link name="link_z_trans"/>
  <link name="link_x_rot"/>
  <link name="link_y_rot"/>
  <link name="link_z_rot"/>
  <link name="offset_wrench">
    <inertial>
      <origin rpy="0 0 0" xyz="0 0 0"/>
      <mass value="0.00987"/>
      <inertia ixx="0.0001" ixy="0" ixz="0" iyy="0.0001" iyz="0" izz="0.0001"/>
    </inertial>
    <visual>
      <geometry>
        <mesh filename="offset_wrench_nogrip.obj"/>
      </geometry>
      <material name="trans_grey"/>
    </visual>
    <collision>
      <geometry>
        <mesh filename="offset_wrench_nogrip.obj"/>
      </geometry>
    </collision>
  </link>
  <joint name="x_trans" type="prismatic">
    <origin rpy="0 0 0" xyz="0 0 0"/>
    <parent link="link_x_trans"/>
    <child link="link_y_trans"/>
    <axis xyz="1 0 0"/>
    <limit effort="100" lower="-10" upper="10" velocity="100"/>
  </joint>
  <joint name="y_trans" type="prismatic">
    <origin rpy="0 0 0" xyz="0 0 0"/>
    <parent link="link_y_trans"/>
    <child link="link_z_trans"/>
    <axis xyz="0 1 0"/>
    <limit effort="100" lower="-10" upper="10" velocity="100"/>
  </joint>
  <joint name="z_trans" type="prismatic">
    <origin rpy="0 0 0" xyz="0 0 0"/>
    <parent link="link_z_trans"/>
    <child link="link_x_rot"/>
    <axis xyz="0 0 1"/>
    <limit effort="100" lower="-10" upper="10" velocity="100"/>
  </joint>
  <joint name="x_rot" type="revolute">
    <origin rpy="0 0 0" xyz="0 0 0"/>
    <parent link="link_x_rot"/>
    <child link="link_y_rot"/>
    <axis xyz="1 0 0"/>
    <limit effort="100" lower="-10" upper="10" velocity="100"/>
  </joint>
  <joint name="y_rot" type="revolute">
    <origin rpy="0 0 0" xyz="0 0 0"/>
    <parent link="link_y_rot"/>
    <child link="link_z_rot"/>
    <axis xyz="0 1 0"/>
    <limit effort="100" lower="-10" upper="10" velocity="100"/>
  </joint>
  <joint name="z_rot" type="revolute">
    <origin rpy="0 0 0" xyz="0 0 0"/>
    <parent link="link_z_rot"/>
    <child link="offset_wrench"/>
    <axis xyz="0 0 1"/>
    <limit effort="100" lower="-10" upper="10" velocity="100"/>
  </joint>
</robot>

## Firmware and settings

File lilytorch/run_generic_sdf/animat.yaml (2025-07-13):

sdf: models/1guilla_v1/sdf/1guilla.sdf
spawn:
  loader: 0
  mode: !!python/object/apply:farms_core.model.options.SpawnMode
  - FIXED
  pose:
  - 0.0
  - 0.0
  - 0.1
  - 0.0
  - 0.0
  - 3.141592653589793
  velocity:
  - 0.0
  - 0.0
  - 0.0
  - 0.0
  - 0.0
  - 0.0
morphology:
  links: []
  self_collisions: []
  joints: []
  n_joints_body: 0
  n_dof_legs: 0
  n_legs: 0
control:
  sensors:
    links: []
    joints: []
    contacts: []
    xfrc: []
    muscles: []
  motors: []

  kinematics_file: positions.csv
  kinematics_sampling: 0.0
  kinematics_indices:
  -
  kinematics_time_index: 0
  kinematics_invert: false
  kinematics_degrees: false
  kinematics_start: 0.0
  kinematics_end: 0.0

name: Animat
show_xfrc: false
scale_xfrc: 1
mujoco: {}

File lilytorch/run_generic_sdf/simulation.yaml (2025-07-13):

units:
  meters: 1.0
  seconds: 1.0
  kilograms: 1.0
timestep: 0.001
n_iterations: 10001
play: false
rtl: 1.0
fast: false
headless: false
show_progress: true
zoom: 1
free_camera: false
top_camera: true
rotating_camera: false
video: false
video_fps: 30
video_speed: 0.2
video_name:
video_yaw: 30
video_pitch: 45
video_distance: 1
video_offset: !!python/tuple
- 0
- 0
- 0
video_filter: null
video_resolution: !!python/tuple
- 1280
- 720
texture_repeat: 3
gravity: !!python/tuple
- 0
- 0
- -9.81
num_sub_steps: 100
n_solver_iters: 10000
residual_threshold: 1.0e-16
visual_scale: 1.0
cone: elliptic
solver: Newton
integrator: implicit
impratio: 10.0
mpr_iterations: 10000
mpr_tolerance: 1.0e-16
noslip_iterations: 0
noslip_tolerance: 1.0e-16
opengl2: false
lcp: si
cfm: 0
erp: 0
contact_erp: 0
friction_erp: 0
max_num_cmd_per_1ms: 1000000000
report_solver_analytics: 0

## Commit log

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2025-05-06 Fixed issues with previous merge for large files
    [1guilla.sdf, link0.obj, link1.obj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]
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2025-05-08 [Project2] Fixed typo in the feedback equation causing division by zero
    [simulation.yaml]
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2025-09-26 Firse tests with IB direct forcing method generate more proper propelled swim - also corrected the com positions from mujoco
    [cylinder.obj]
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2025-10-28 implemented rectangular grids and fixes few plotting alignments in staggered grid
    [1guilla.sdf, 1guilla_old.sdf]
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2025-10-29 reverting to farms2 branch
    [animat.yaml]
2025-10-29 cleaning+testing new multianimats installation - still broken
    [1guilla.sdf, arena_flat.sdf, arena_water.sdf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]
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2025-11-10 switching to older commit to check previous cylinder error tests
    [sphere.sdf]
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2026-03-03 added new sdf with base moved to 1st link to allow fixed rotations around first joint
    [1guilla_link1_base.sdf]
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2026-03-09 Refactor 3D solver, add benchmarks & video comparison pipeline; remove legacy modules
    Solver & numerics:
    - Major rework of BDIMhandler for 3D (mu/normals recompute, field release)
    - Overhaul body.py (BodyAnalytical 3D support, lazy properties)
    - Extend poisson_mult with RBGS smoother, torch.compile support, variable coefficients
    - Extend poisson_fft for 3D domains
    - Refactor solver.py (Heun integration, force methods, 3D fluid step)
    - Remove deprecated diffusion.py, dynamic_water.py, poisson_petsc.py
    Benchmarks & profiling:
    - Add run_compile_advdiff_bench.py (torch.compile on adv-diff + BDIM)
    - Add run_compile_smoother_bench.py (Jacobi vs RBGS, eager vs compiled)
    - Add run_poisson_compariso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
    [arena_water.sdf, pool.sdf]
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2026-03-17 fixed pipeline for generating stacked video
    [arena_water.sdf, pool.sdf]
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2026-03-30 fixed issues with gazzola sphere experiment - porting to BDIMhandler extension class
    [sphere.sdf, up.csv, up_old.csv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]
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2026-04-22 Fix Projection double-count (3c→"3c ") + add README with improvements
    Agent-Logs-Url: https://github.com/ferrarioa5/lilytorch/sessions/aabf97ed-a4ff-4507-a19d-220be3b6b363
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2026-04-28 fixed new nbforces_opt method run locally (using gpus)
    [arena_water.sdf, pool.sdf]
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2026-04-29 corrected carreau for running the 1guilla free swim simulation
    [arena_water.sdf, pool.sdf]
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2026-04-30 make salamander 2d sim work - pressure zero inside bug
    [arena_water.sdf, pool.sdf]
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2026-04-30 polish: docs — fix stale run_cost_analysis_3d.py ref, sync src/ layout (forces, extras, kernels, configs)
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2026-05-01 optimize fused SDF+force memory: skip dead caches, persist buffers, drop D2H sync
    Agent-Logs-Url: https://github.com/ferrarioa5/lilytorch/sessions/3ab75298-467d-4853-989d-d6d3bf8a63c3
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2026-05-03 Reject force_method='method1' in 2-D kernel mode (incompatible with streaming/fused forces kernels)
    Agent-Logs-Url: https://github.com/ferrarioa5/lilytorch/sessions/c6052ebe-c8d3-4f39-a1bf-0a1c7ee5876d
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2026-05-05 Fix fused 2D force stencils to match kernels path and add direct parity test
    Agent-Logs-Url: https://github.com/ferrarioa5/lilytorch/sessions/19399980-a8b9-4fc2-9690-d4d9f0e7ea2c
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2026-05-05 fix(BDIM 2-D fused): seed lagged CC normals before SDF reset
    Agent-Logs-Url: https://github.com/ferrarioa5/lilytorch/sessions/eef9c378-2270-4b25-b724-e300dd1faf07
2026-05-05 fixed streming order
    [arena_water.sdf, pool.sdf]
2026-05-05 fixed 2d fused approach
    [arena_water.sdf, pool.sdf]
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2026-05-06 fixing cost analysis in 2d
    [arena_water.sdf, pool.sdf]
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2026-05-07 fixed bugs with BDIMhandler + todo list update
    [arena_water.sdf, pool.sdf]
2026-05-07 fixed cost analysis runs
    [arena_water.sdf, pool.sdf]
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2026-05-08 Step 3: unify forces leaves for 2-D/3-D
    Replace four near-duplicate kernels (_forces_shared_2d/3d,
    _forces_body_batch_2d/3d) with two dim-agnostic helpers (_forces_shared,
    _forces_body_batch) plus thin shape-specialized wrappers.
    Wrappers retain identical signatures and module-level names so callers
    in solver.py (and the per-D torch.compile bindings) need no change —
    each compiled artifact still sees a fully unrolled, shape-specialized
    graph because the wrappers fix the component count at trace time.
    Numerical equivalence verified to <1e-12 against legacy implementations
    on randomized 2-D and 3-D inputs (including Towers grad-mag correction).
    Net diff: -135 lines.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
2026-05-11 fixed scaling of all except other
    [arena_water.sdf, pool.sdf]
2026-05-12 fixing installation + flow viz on laptop
    [arena_water.sdf, pool.sdf]
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2026-05-12 fixed poisson compilation and paddling mode for the gamepad
    [arena_water.sdf, pool.sdf]
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2026-05-19 new cuda/c++ multigrid kernels+fixed bcs+removed poisson_compile - unnecessary via kernel mode
    [arena_water.sdf, pool.sdf]
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2026-05-20 fixed flow viewer camera save and working on zebrafish speed match - adding pd controller
    [joints_positions_fast.xlsx, joints_positions_slow.xlsx]
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2026-05-21 fixed sky and viz
    [arena_water.sdf, pool.sdf]
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2026-05-26 adjusted variable coefficient formula + error computation
    [arena_water.sdf, pool.sdf]
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2026-05-29 lagrangian forces: world-frame refresh, sample offset, FSI under-relaxation
    - BDIMhandler: refresh body.cnt_update (2D) and tri_centroid_world /
    tri_normal_world (3D) into world coords each step when
    force_method='lagrangian'. Previously these were left at the
    body-local init frame in the streaming/kernel-mode update paths, so
    the Lagrangian kernels sampled fluid fields at the wrong locations
    (~zero forces in 3D, bogus-but-finite in 2D → mjWARN_BADQACC).
    - BDIMhandler: enforce CCW contour orientation once per body (kernel
    assumes outward normal nx=ty, ny=-tx); detect via signed area and
    flip if needed. Mesh-derived bodies are often CW.
    - lagrangian kernels (CUDA + CPU, 2D/3D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
    [arena_water.sdf, ep223_Cl1_fast_fish13_model_angles.xlsx, ep248_Cl2_slow_fish13_model_angles.xlsx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]
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2026-06-01 added body div correction +speeding up lagrangian force computations
    [arena_water.sdf, cvx1_relax1_zpi1.csv, pool.sdf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]
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2026-06-01 fixing implicit coupling
    [arena_water.sdf, pool.sdf]
2026-06-01 Fix BDIM2 FFT-projection explosion in coupled sims (f650945 regression)
    The FFT pressure projection divided the Poisson RHS by the mu0-weighted
    staggered coefficient (div/ch). In kernel mode ch = _ch_persist =
    dt*mu0/rho_eff, which -> 0 across the immersed-boundary transition band,
    making div/ch singular there. The constant-coefficient FFT solver cannot
    represent that, so pressure and velocity blew up exponentially
    (~1.5e5x/step), aborting coupled runs around iteration 5 (e.g.
    single_sphere_drop_coquerelle). Introduced by f650945 (which made
    bdim_mu0_projection default True).
    project(): the FFT RHS now always divides by the bounded scalar
    coeff = w*dt/rho when the coefficient is a tensor; t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
2026-06-01 docs: implicit-coupling guide + BDIM FFT fix writeup; Sphinx docstring cleanup
    Documentation
    - New docs/strong_coupling.rst: strong (implicit) FSI coupling — the
    added-mass instability, the fixed-point residual formulation, the
    Aitken and IQN-ILS accelerators (with equations), the Option-A coupled
    step (checkpoint/restore + commit converged force), and usage for both
    the coupled (body.coupling YAML / BaseSimConfig.coupling) and standalone
    paths. Added to the index toctree.
    - immersed_boundary.rst: expanded the BDIM pressure-projection section —
    mu0-weighted projection, the variable-density (rho_eff) extension, and a
    new "Multigrid vs FFT" subsection explaining why the FFT R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
2026-06-02 implicit coupling: robustness — never crash on a non-converging step
    On articulated / position-controlled swimmers with force_method='lagrangian'
    (e.g. 1guilla full pool) the fluid-load response to the per-link force is
    near-discontinuous, so IQN-ILS oscillates instead of converging. After a
    number of oscillating sweeps the QR least-squares became ill-conditioned and
    produced a runaway iterate (force ~1e6), which was applied to MuJoCo,
    teleported the body out of the domain, and crashed the streaming kernel with
    a negative dirty-region AABB ("negative dimension").
    _step_implicit now:
    - guards every candidate force before applying it (rejects non-finite or
    norm > force_bound x running-max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
2026-06-02 modified 1guilla full pool - broken mgcg
    [arena_water.sdf, pool.sdf, scaling_kernel_b01_multigrid.csv]
2026-06-02 fixing 1guilla colors
    [pool.sdf]
2026-06-02 free surface: gauge + air-extension + FFT fix; adv_diff split; jellyfish FS example
    Advection/diffusion refactor
    - Split adv_diff.py -> advection.py (schemes, _flux, advect_momentum,
    new advect_scalar, AdvDiffSolver) + diffusion.py (laplacian/diffuse).
    adv_diff.py kept as legacy (unused). Numerically bit-identical to the
    old AdvDiffSolver across all schemes, 2D/3D, const+variable nu, set_BCs.
    - solver.py/test import AdvDiffSolver from advection.
    Free surface
    - FreeSurface.advect now uses the shared convective schemes via
    advect_scalar (conservative flux form) instead of bespoke 1st-order
    upwind; convection_method config knob.
    - interface_gauge_offset: anchor the pressure datum at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
2026-06-02 jellyfish FS config: fix 256^3 conditioning + ~6x speedup
    - bdim_mu0_projection: False — the mu0-weighted projection coefficient
    (c = mu0*dt/rho -> 0 in the body) combined with the free-surface GFM
    scaling makes the MGCG operator ill-conditioned; at 256^3 the thin bell
    shell samples mu0 ~0 so it blows up immediately (it~2-3, dt-independent).
    The bounded coefficient c = dt/rho is well conditioned (no-slip re-imposed
    each step by BDIM). Confirmed: 256^3 single-phase (fft) is stable, so it
    was the FS/mgcg path. (More MGCG cycles only papered over it at 64^3.)
    - Banded velocity extension (extend_full: false, extend_iters: 8): the old
    full extension did 2*max(grid) full-grid sweep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
2026-06-02 free surface: fix near-surface instability — extend velocity on a copy, not in place
    The velocity extension in _fs_post_step was overwriting the solver's
    projected (divergence-free) u/v/w in the air band with a
    constant-along-normal (non-div-free) extrapolation. The interface cut
    cells read that air-side face velocity in their divergence stencil, so it
    re-injected divergence at the surface every step; under gravity, with the
    body's flow forcing the surface, this fed a growing near-surface velocity
    mode -> MGCG degradation -> blow-up (~it=99 at 256^3; slower at 128^3).
    Isolation: extension OFF is stable but the surface stays flat (no
    tracking); advection/reinit alone are stable; only the in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
2026-06-02 free surface: unified GFM+BDIM — body-aware so a body can cross the interface
    When an immersed body reaches the free surface, the GFM (free-surface
    p=p_atm BC) and BDIM (body no-slip) were two independent interface models
    keying off phi_fs only: the GFM treated body-occupied cells as plain
    water/air (pinned them to p_atm, computed a bogus water-fraction theta)
    while BDIM imposed the body velocity there — they clobbered each other's
    pressure BC and the solve blew up at the crossing.
    Make the free-surface ops body-aware (solid_cc = composite_body.sdf_val<0),
    deferring to BDIM wherever the body is:
    - ghost_fluid_face_scales(solid_cc): faces touching a body cell get scale=1
    (BDIM coeffici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
2026-06-02 jellyfish 256³ free-surface: body-div correction + vanLeer TVD fix the bell-shell blow-up
    The submerged-jellyfish + free-surface run blew up at 256³ (~it=123) while
    192³ was stable — a resolution-dependent runaway localized at the deforming
    bell shell (surface quiet, MGCG converging, rigid body velocity bounded).
    Two config-only fixes (no solver code change):
    1. bdim_body_div_correction: True — the bell DEFORMS, so the body velocity
    carries ∇·u_b ≠ 0. Without the Maertens–Weymouth body-div RHS source the
    projection forces ∇·u=0 inside the bell, fighting the contraction; that
    spurious shell response sharpens with resolution. (Pushed the blow to
    ~it=145.)
    2. c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
2026-06-03 fixes to removing old cost anaylysis + particle viewer + old single phase flow free surface modeling
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2026-06-05 BDIM: remove rho_body from the projection; clean up + rename coefficient kernels
    The immersed-body density no longer enters the fluid projection. The BDIM
    Poisson coefficient is now the constant-density Weymouth & Yue form
    `c = dt*mu0/rho_fluid` everywhere (the body enters only through mu0); body
    weight/buoyancy is the coupling's concern (MuJoCo mass + the external
    Archimedes term in BDIMhandler, which uses the animat density).
    - solver.py + CUDA/CPU kernels: coefficient -> dt*mu0/rho_fluid; FluidSolver
    no longer reads `rho_body` (config key now ignored). FFT cases unchanged
    (scalar dt/rho); single-phase MGCG now rho_body-independent (verified).
    - Deleted dead per-body-density plumbing: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
2026-06-05 fixing files
    [SYSSER01_surface.igs, SYSSER02_surface.igs, SYSSER03_surface.igs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]
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2026-06-05 perf/diagnostics: T1a+T1b memory trims, K9/K10 kernel nits, FlowDiagnostics wired, 3D mem benchmark
    Memory/perf (optimize_speed_memory):
    - T1b: project() uses a local `div` (was persistent self.div), del'd right
    after each Poisson solve so it is freed before the correction allocations.
    - T1a: inline `_tvd_face` into van_leer/abdquickest/cubista (advection.py),
    chaining in-place on `psi` and reusing the live `denom`; `_tvd_face` removed.
    Bit-exact (fp32+fp64, incl. denom~0 branch).
    Kernel parity nits (rebuild _C.so via build.sh to take effect):
    - K9: apply_bcs_2d_cuda gains the is_cuda TORCH_CHECK (mirrors 3D).
    - K10: apply_bcs_2d/3d kernels compute src_lin unconditionally (Dirichlet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
2026-06-05 cleanup: remove legacy adv_diff.py; log per-step hot-path overhead findings
    - Delete lilytorch/src/adv_diff.py (the pre-split monolith). Its lone importer,
    run_compile_advdiff_bench.py, is repointed to lilytorch.src.advection — a
    drop-in swap (identical AdvDiffSolver constructor/solve API). Fix the
    "kept on disk as legacy" docstrings in advection.py / diffusion.py.
    - to_do_list.md: record per-step hot-path observations found while doing
    T1/diagnostics (all "measure first"):
    H1 finalize_step calls torch.cuda.empty_cache() every step (allocator churn);
    H2 check_explosion does a device->host sync every step (pipeline stall);
    H3 diagnostics_every=100 is now default-on — ratify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
2026-06-07 fixing boat sim
    [arena_water.sdf, toy_boat.sdf]
2026-06-09 fixing explosions in two phase model
    [_ball_composite.obj, _ctrl_sphere_composite.obj, _ctrl_spheroid_composite.obj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]
2026-06-10 working two-phase flow boat sim with two propellers, correct mass, better propeller, and various runs to verify
    [_massx_toy_boat_hullonly_full.sdf, arena_water.sdf, pool.sdf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]
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2026-06-10 fixeed iqn-ils solver + 1guilla 2d sims
    [arena_water.sdf, pool.sdf]
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2026-06-14 MP11: pipelined CG — keep alpha/beta on-device to cut Poisson CG syncs
    The native mgcg/rmgcg CG loop did ~4 host .item() D->H syncs per iteration
    (alpha x2, beta, residual-norm), stalling the CPU<->GPU pipeline and leaving
    small/2D solves at ~23% GPU-util. Keep alpha/beta as 0-dim device scalars and
    fuse the axpy updates with addcmul_/mul_ (a 0-dim tensor broadcasts -> same
    kernel count, no extra temps): x+=a*d, r-=a*q, d=b*d+z. Only the residual-norm
    check still syncs (~1/iter, as targeted). Applied to all 4 drivers
    (mgcg/rmgcg x 2D/3D).
    ~1.13-1.18x wall-clock on sync-bound small-2D solves (N=32/64/128). Parity:
    rmgcg(kdef=0) still bit-identical to mgcg (0.00e+00); all 3 Poisson self-tes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
2026-06-14 GPU-util (GU5): fuse per-axis Neumann BC into one kernel launch
    Re-profiling the native CUDA Poisson path (post native-port + MP11) showed it is
    launch-latency bound, not Python-dispatch or sync bound: the C++ V-cycle issues
    ~2100 tiny kernels per solve and the GPU idles between launches (idle ~=
    #launches x 1.5us). The single largest launch-count contributor was the Neumann
    BC mirror, launched once PER AXIS PAIR (3 kernels in 3D) by every smoother
    half-sweep and residual eval (~1170 launches/solve at 3D N=96).
    Fuse the axis passes into ONE launch via blockIdx.{y,z} as the axis-pair
    selector. Safe because the 5-/7-point stencils read only FACE ghosts: each axis
    pair writes a disjoint interi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
2026-06-14 Poisson: add sync-free mode (tol<0) to enable CUDA-graph capture
    tol < 0 disables the per-iteration residual-norm early-exit: the .item() D->H
    sync is skipped via short-circuit so the whole native solve becomes host-sync-
    free and can be captured/replayed in a CUDA graph (runs the full max_cycles
    budget). Backward-compatible: tol >= 0 keeps the exact current behaviour, so
    multigrid/mgcg/rmgcg self-tests still PASS bit-for-bit.
    Applied to all 6 drivers (multigrid/mgcg/rmgcg x 2D/3D). This is the prerequisite
    flagged in MP11/GU6 for graphing the Poisson solve.
    POC (graph_poc) at production cycle count (mc=3), fp32, vs eager+sync:
    2D N=64 2.05x 2D N=128 1.53x 3D N=48 1.49x (graph win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
2026-06-15 two-phase: fix eulerian force over-prediction via body-anchored pressure
    The two-phase eulerian band force integral -Σ p·n·δ is gauge-invariant
    only if the discrete Σ n·δ = 0, which fails for a coarsely-resolved body.
    So the DC pressure level at the body leaks into a spurious force
    ≈ -p_baseline · Σ n·δ. In single-phase that baseline is the small dynamic
    pressure (~10 Pa) and the leak is negligible; in two-phase it is the
    hydrostatic head + the unpinned all-Neumann gauge (~hundreds-to-thousands
    of Pa), so it swamps the real load — a static body acquires a large fake
    force and an undulating swimmer a fake thrust (the surface-pool eel swam
    unrealistically fast vs the single-flui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
2026-06-15 GU6: CUDA-graph capture of the native Poisson solve (small-grid win)
    Replays the ~1300-kernel native mgcg/multigrid V-cycle with ~1 host
    launch on launch-bound small grids. Wired entirely inside PoissonSolver:
    _solve_mgcg_native/_solve_multigrid_native route through a new
    _graphed_native_solve when enabled, which lazily captures one CUDA graph
    per (method, ndim, input-shape) into static p/f/face buffers (via
    _capture_poisson_graph), then each step copy_'s the live RHS + BDIM face
    coeffs + warm-start guess in, replays, and copies p back out (residual
    cloned). Capture failure -> permanent eager fallback. Eager and graphed
    paths share one _native_call dispatcher. Relies on the existing tol<0
    sy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
2026-06-16 surface-pool: refine grid, stability cap, BDIMhandler updates + parity tests
    - gen_config_surface_pool.py: refined grid (1200x600x104, x in [2,6]),
    poisson_method/force_method tuning, and rho_air density-ratio cap (1.2->12.5,
    80:1) that fixes the high-density-ratio two-phase blow-up at the refined grid
    (833:1 NaNs at the waterline once the interface sharpens; 80:1 stays bounded).
    - BDIMhandler.py: streaming/update changes (+ python/streaming parity tests).
    - pool / arena_water SDFs and milestones notes updated.
    [arena_water.sdf, pool.sdf]
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2026-07-01 warp port
    [arena_water.sdf, pool.sdf]
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2026-07-02 warp: remove python/kernel solver modes; fix Poisson ghost-ring gauge leak
    Collapse the solver_method python/kernel split into a single fused,
    body-agnostic step path:
    - Rename Kernel A/B -> body_update_{2,3}d / bdim_forcing_{2,3}d. The body
    update is launched from BDIMhandler._launch_body_update; the solver
    consumes only the composite-body contract (sdf_val, sdf_val_u/v[/w],
    body_u/v[/w], optional bdim_dirty/bdim_keys/bdim_fields_scratch) and has
    no Kernel-A knowledge left.
    - fluid_step dispatches to _fluid_step_fused_{2,3}d only; solver_method /
    use_kernels are deprecated no-ops (warn, keep configs loading). Delete
    BDIMhandler._update_python + contour-mask application and the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
    [arena_water.sdf, pool.sdf]
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2026-07-08 refactor: Task 7 — remove per-kernel graph capture, unify diffusion/ops/strain-rate as pure Warp kernels
    Drop the re-entrancy flag (in_capture/capturing/_DEPTH) from graph_capture.py;
    per-kernel runners (SL advection, diffusion, bdim_forcing, apply_bcs) are now
    pure launch wrappers — their raw wp.launch calls are recorded by the outer
    WholeStepGraphRunner's wp.ScopedCapture, removing the nested capture_launch
    hazard (CUDA error 900) that the flag previously guarded against.
    Key changes:
    - graph_capture: WholeStepGraphRunner gains use_cuda_graph toggle and
    _graph_capture_debug flag; in_capture/capturing context manager removed.
    - diffusion: merge constant/variable Laplacian kernels int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
    [arena_water.sdf, pool.sdf]
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2026-07-14 wip: in-flight amphibious ramp / pool SDF / zebrafish controller changes
    Uncommitted working-tree work, committed as-is so the Poisson fix lands in a
    separate commit and the tree is clean enough to switch branches.
    [arena_water.sdf, pool.sdf]
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2026-07-15 fix: CUDA graph capture never triggered — key instability from two bugs
    Root cause: the graph key changed every step, so the 4-sighting
    capture threshold was never reached. Two bugs caused persistent
    BDIM buffers to be reallocated every step:
    1. _cached_float (solver.py): skipped cache for non-tensor scalars,
    causing _dt_over_rhofluid to differ at 16th decimal digit between
    init and per-step paths.
    2. Device comparison cuda:0 != cuda (BDIMhandler.py + solver.py):
    self.device = torch.device('cuda') but tensors report .device as
    'cuda:0'. Direct != comparison always true → realloc every step.
    Fixes:
    - _cached_float: always check cache first (remove early-return)
    - All need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
    [arena_water.sdf, pool.sdf, ramp.sdf]
2026-07-16 fix: improve Poisson convergence for large immersed bodies
    Two changes to prevent the multigrid solver from stalling when a
    wall-to-wall body (e.g. amphibious ramp) creates a large region of
    degenerate or highly-contrasted Poisson coefficients:
    1. poisson_mult.py: raise jcap_tol from 1e-12 to 1e-7
    Masks cells where the diagonal J < 1e-7 from the smoother,
    preventing wasted iterations on body-interior cells where
    the operator is nearly singular.
    2. two_phase_solver.py: clamp Poisson coefficients to a floor of
    1e-6 (= dt/ρ_water) inside the body.
    The operator div(μ₀·dt/ρ·grad(p)) becomes singular when μ₀→0
    inside large bodies. Clamping prevents the singularity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
    [drag_coefficients.csv, ep223_Cl1_fast_fish13_XY_BL.csv, ep223_Cl1_fast_fish13_cumAngles_deg.csv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]
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2026-08-10 Prepare repository for publication
    Move the reference-data folder to the examples repository and tidy the
    packaging and ignore rules ahead of the first public release.
    - data_to_save/ moves to lilytorch_examples, where its only three consumers
    live. Two of them already resolved paths to the examples repository root,
    so they were reading a non-existent directory until now.
    - setup.py keeps only what declarative metadata cannot express: compiling
    lilytorch.src._C against the runtime PyTorch. Name, version, authors,
    packages and the rest were duplicated in pyproject.toml and now live
    there alone. include-package-data and zip-safe move with them.
    - Package discovery lists the four rea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
    [height_evolution_bergmann.csv, koumoutsatokos_keonard_1995.csv, up.csv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]
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
